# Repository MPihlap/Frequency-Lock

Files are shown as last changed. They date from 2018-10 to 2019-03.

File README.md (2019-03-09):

# Frequency-Lock

## Demonstration video:
https://www.youtube.com/watch?v=SHbAAHV13OE

## Overview
Result of a hardware project done for a course at University of Tartu. It is a custom board design built around the STM32F4 microcontroller. 
The system records audio in 0.2 second buffers, performs RFFT and analyzes the output to see if the correct note is being played.

The code is fully compatible with the STM32F4 Discovery board.

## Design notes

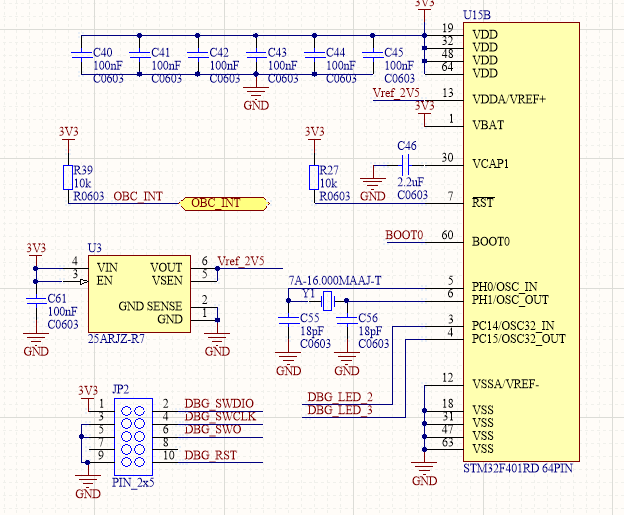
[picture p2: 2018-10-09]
docs/ˇF4power.PNG

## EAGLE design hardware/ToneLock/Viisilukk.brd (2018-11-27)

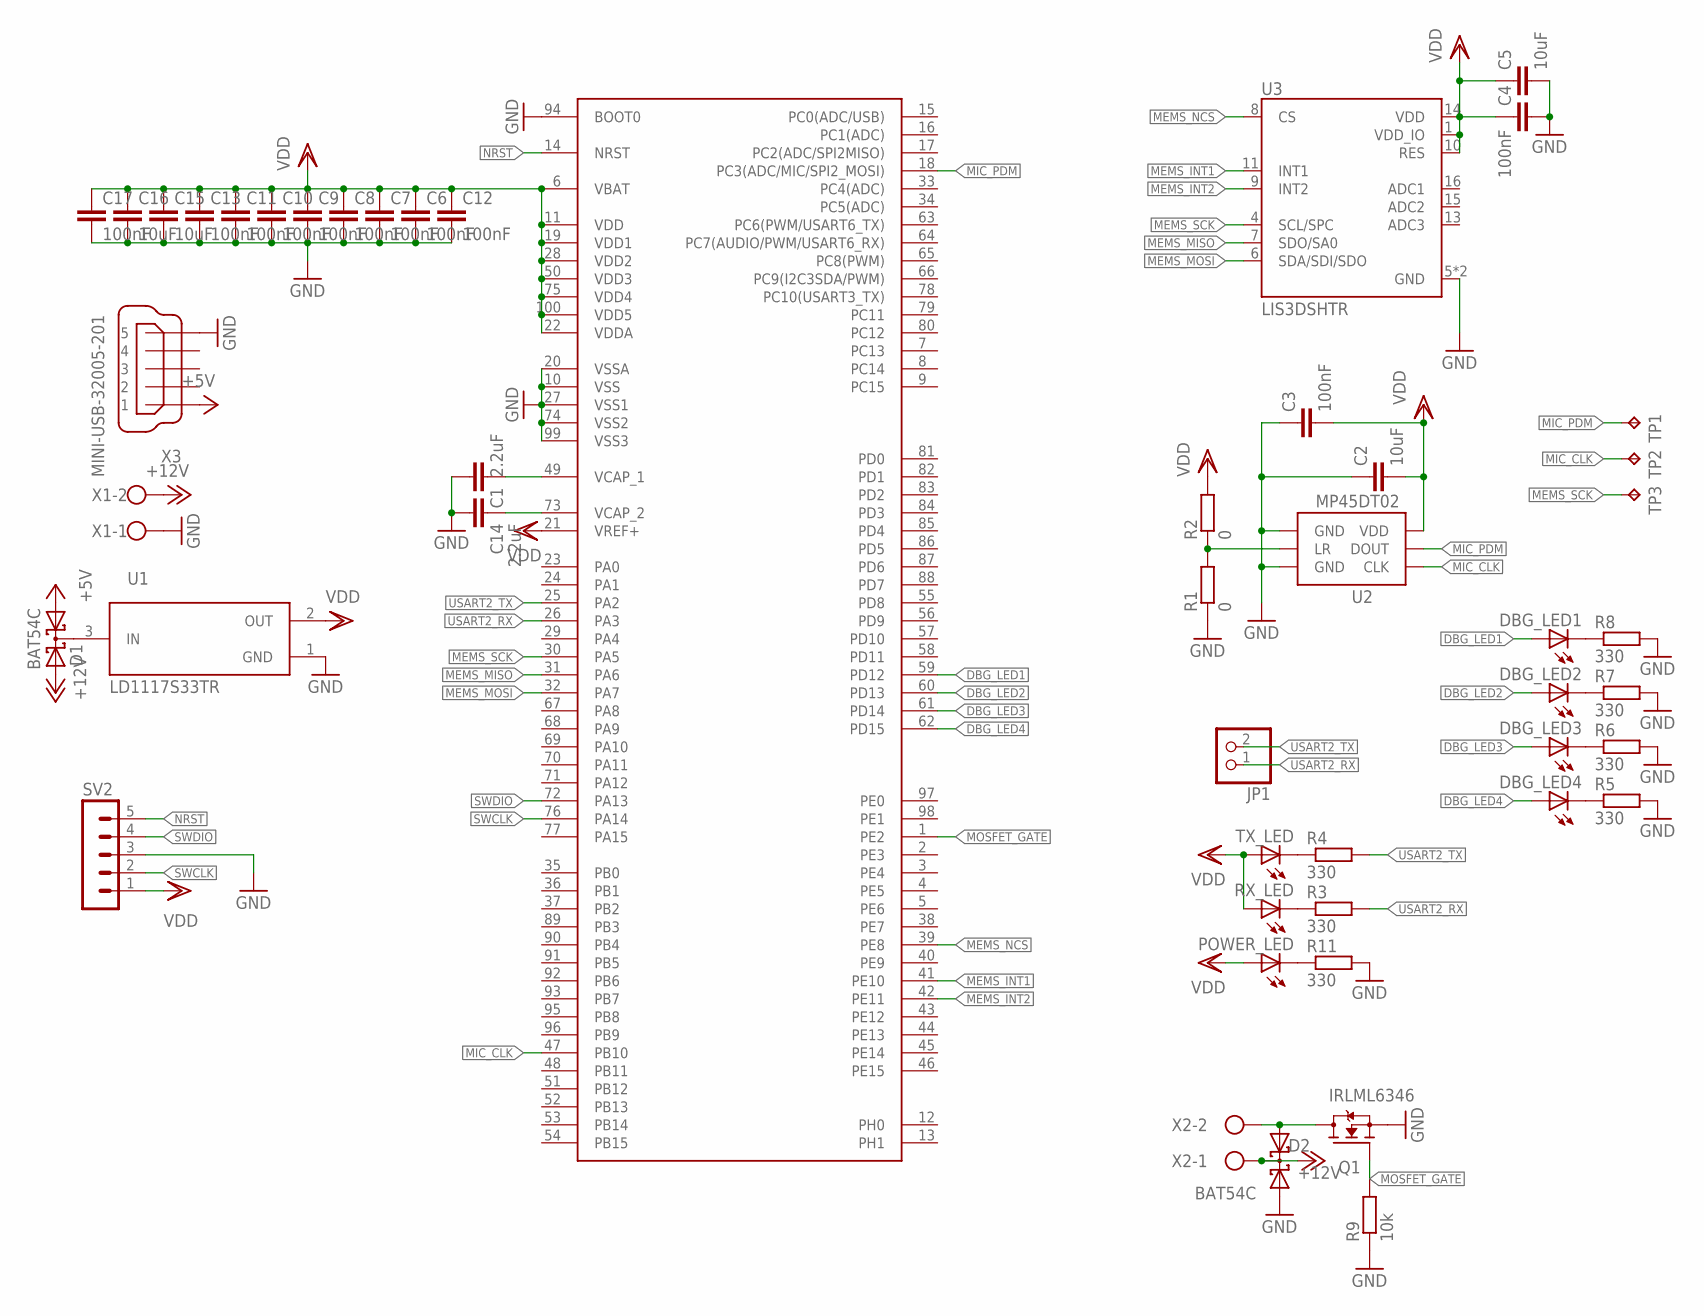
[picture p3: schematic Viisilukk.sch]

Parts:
C1, C14: 2.2uF; C0603
C2, C5, C15, C16: 10uF; C0805
C3, C4, C6, C7, C8, C9, C10, C11, C12, C13, C17: 100nF; C0603
D1, D2: BAT54C; SOT23
DBG_LED1, DBG_LED2, DBG_LED3, DBG_LED4: LEDCHIP-LED0603; CHIP-LED0603
JP1: PINHD-1X2; 1X02
POWER_LED: LEDCHIP-LED0603; CHIP-LED0603
Q1: IRLML6346; SOT23
R1, R2: 0; R0603
R3, R4, R5, R6, R7, R8, R11: 330; R0603
R9: 10k; R0603
RX_LED: LEDCHIP-LED0603; CHIP-LED0603
SV2: MA05-1
TP1, TP2, TP3: TPB2,54; B2,54
TX_LED: LEDCHIP-LED0603; CHIP-LED0603
U1: LD1117S33TR; SOT230P700X180-4N
U2: MP45DT02; ST_HLGA6
U3: LIS3DSHTR; LGA16R50P5X3_300X300X100N
U$1: STM32F407STM32D40X; LQFP100
X1, X2: W237-102
X3: MINI-USB-32005-201; 32005-201

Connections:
+5V: D1.1 (A1), X3.1
+12V: D1.2 (A2), D2.3 (CC), X1.2, X2.1
DBG_LED1: DBG_LED1.A, U$1.59 (PD12)
DBG_LED2: DBG_LED2.A, U$1.60 (PD13)
DBG_LED3: DBG_LED3.A, U$1.61 (PD14)
DBG_LED4: DBG_LED4.A, U$1.62 (PD15)
GND: C1.2, C2.1, C3.1, C4.2, C5.2, C6.2, C7.2, C8.2, C9.2, C10.2, C11.2, C12.2, C13.2, C14.2, C15.2, C16.2, C17.2, D2.1 (A1), Q1.2 (S), R1.1, R5.2, R6.2, R7.2, R8.2, R9.1, R11.2, SV2.3, U1.1 (GND), U2.1 (GND), U2.3 (GND), U3.5 (GND), U3.12 (GND), U$1.10 (VSS), U$1.20 (VSSA), U$1.27 (VSS1), U$1.74 (VSS2), U$1.94 (BOOT0), U$1.99 (VSS3), X1.1, X3.5
MEMS_INT1: U3.11 (INT1), U$1.41 (PE10)
MEMS_INT2: U3.9 (INT2), U$1.42 (PE11)
MEMS_MISO: U3.7 (SDO/SA0), U$1.31 (PA6)
MEMS_MOSI: U3.6 (SDA/SDI/SDO), U$1.32 (PA7)
MEMS_NCS: U3.8 (CS), U$1.39 (PE8)
MEMS_SCK: TP3.TP, U3.4 (SCL/SPC), U$1.30 (PA5)
MIC_CLK: TP2.TP, U2.4 (CLK), U$1.47 (PB10)
MIC_PDM: TP1.TP, U2.5 (DOUT), U$1.18 (PC3(ADC/MIC/SPI2_MOSI))
MOSFET_GATE: Q1.1 (G), R9.2, U$1.1 (PE2)
unnamed: POWER_LED.C, R11.1
unnamed: C14.1, U$1.73 (VCAP_2)
unnamed: R1.2, R2.1, U2.2 (LR)
unnamed: R3.1, RX_LED.C
unnamed: C1.1, U$1.49 (VCAP_1)
unnamed: D1.3 (CC), U1.3 (IN)
unnamed: R4.1, TX_LED.C
unnamed: DBG_LED4.C, R5.1
unnamed: DBG_LED3.C, R6.1
unnamed: DBG_LED2.C, R7.1
unnamed: DBG_LED1.C, R8.1
unnamed: D2.2 (A2), Q1.3 (D), X2.2
NRST: SV2.5, U$1.14 (NRST)
SWCLK: SV2.2, U$1.76 (PA14)
SWDIO: SV2.4, U$1.72 (PA13)
USART2_RX: JP1.1, R3.2, U$1.26 (PA3)
USART2_TX: JP1.2, R4.2, U$1.25 (PA2)
VDD: C2.2, C3.2, C4.1, C5.1, C6.1, C7.1, C8.1, C9.1, C10.1, C11.1, C12.1, C13.1, C15.1, C16.1, C17.1, POWER_LED.A, R2.2, RX_LED.A, SV2.1, TX_LED.A, U1.2 (OUT), U2.6 (VDD), U3.1 (VDD_IO), U3.10 (RES), U3.14 (VDD), U$1.6 (VBAT), U$1.11 (VDD), U$1.19 (VDD1), U$1.21 (VREF+), U$1.22 (VDDA), U$1.28 (VDD2), U$1.50 (VDD3), U$1.75 (VDD4), U$1.100 (VDD5)

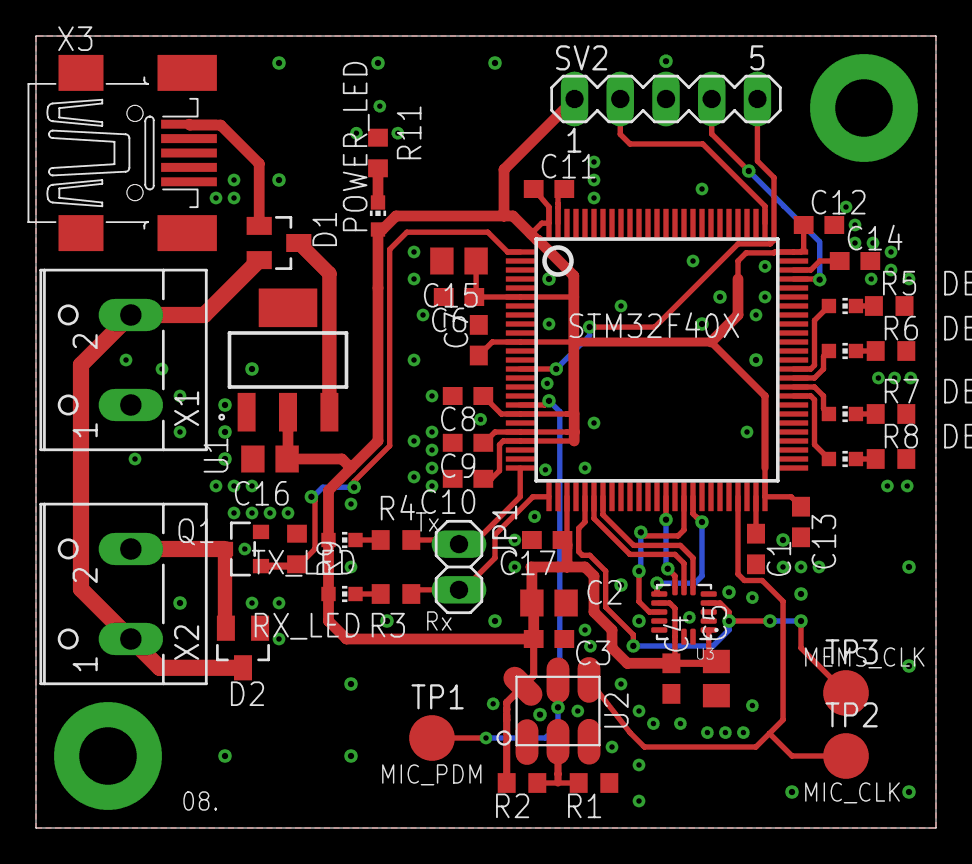
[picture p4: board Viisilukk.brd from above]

Board: 2 copper layers, 50.0 x 44.0 mm, 49 parts (0 on the bottom side), 34 nets.

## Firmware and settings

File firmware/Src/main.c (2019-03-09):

/**
  ******************************************************************************
  * @file           : main.c
  * @brief          : Main program body
  ******************************************************************************
  * This notice applies to any and all portions of this file
  * that are not between comment pairs USER CODE BEGIN and
  * USER CODE END. Other portions of this file, whether
  * inserted by the user or by software development tools
  * are owned by their respective copyright owners.
  *
  * Copyright (c) 2019 STMicroelectronics International N.V.
  * All rights reserved.
  *
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
  ******************************************************************************
  */
/* Includes ------------------------------------------------------------------*/
#include "main.h"
#include "stm32f4xx_hal.h"
#include "pdm2pcm.h"

/* USER CODE BEGIN Includes */
#include "arm_math.h"
#include <math.h>
#include "note_freq.h"
/* USER CODE END Includes */

CRC_HandleTypeDef hcrc;

I2S_HandleTypeDef hi2s2;

SPI_HandleTypeDef hspi1;

TIM_HandleTypeDef htim6;

UART_HandleTypeDef huart2;

/* USER CODE BEGIN PV */

/* USER CODE END PV */

void SystemClock_Config(void);
static void MX_GPIO_Init(void);
static void MX_SPI1_Init(void);
static void MX_USART2_UART_Init(void);
static void MX_I2S2_Init(void);
static void MX_CRC_Init(void);
static void MX_TIM6_Init(void);

/* USER CODE BEGIN PFP */
// static void SPI2_NVIC_INIT(void);
/* USER CODE END PFP */

/* USER CODE BEGIN 0 */
uint16_t PDM_BUF_1[PDM_BUF_SIZE];  // PDM buffer1
uint16_t PCM_BUF_1[PCM_BUF_SIZE];  // PCM buffer1
uint16_t PCM_BUF_2[PCM_BUF_SIZE];  // PCM buffer2
float32_t fft_output_buffer[PCM_BUF_SIZE * 2];
float32_t fft_input_buffer[PCM_BUF_SIZE];
float32_t fft_mag_buffer[PCM_BUF_SIZE];
uint32_t local_pcm_pointer = 0;  // Keeps track of PCM buffer
uint8_t PCM_switch_flag = 0;
uint16_t *current_PCM_buffer;  // Pointer to array to be recorded to
uint8_t RECORD_ENABLE = 0;     // Recording control flag
uint8_t open_lock_counter = 0;
uint32_t sequence[] = MY_HEART_WILL_GO_ON;
// Desired index of maximum magnitude, initially 100 = 781.25 ... 789 Hz
uint32_t desiredIndex = 100;
uint16_t error = 3;  // How many neighbouring indexes will be considered legit
arm_rfft_fast_instance_f32 S;

/* USER CODE END 0 */

/**
  * @brief  The application entry point.
  *
  * @retval None
  */
int main(void) {
  /* USER CODE BEGIN 1 */
  //__HAL_DBGMCU_UNFREEZE_IWDG();
  /* USER CODE END 1 */

  /* MCU
   * Configuration----------------------------------------------------------*/

  /* Reset of all peripherals, Initializes the Flash interface and the Systick.
   */
  HAL_Init();

  /* Configure the system clock */
  SystemClock_Config();

  /* Initialize all configured peripherals */
  MX_GPIO_Init();
  MX_SPI1_Init();
  MX_USART2_UART_Init();
  MX_I2S2_Init();
  MX_CRC_Init();
  MX_PDM2PCM_Init();
  MX_TIM6_Init();
  /* USER CODE BEGIN 2 */
  arm_rfft_fast_init_f32(&S, PCM_BUF_SIZE);
  desiredIndex = GET_DESIRED_INDEX(sequence[open_lock_counter]);
  error = ERROR_INDEX(sequence[open_lock_counter]);
  LOCK_ENABLE();
  // SPI2_NVIC_INIT();
  HAL_GPIO_WritePin(GPIOE, SPI1_NCS_PIN, GPIO_PIN_SET);
  RECORD_ENABLE = 1;  // Enable I2S reading
  HAL_GPIO_WritePin(LED_PORT, LED2_PIN, GPIO_PIN_SET);
  uint8_t PCM_switch_prev = PCM_switch_flag;

  current_PCM_buffer = PCM_BUF_1;
  volatile float32_t maxmag;
  volatile uint32_t index;

  HAL_I2S_Receive_IT(&hi2s2, PDM_BUF_1, 64);

  /* USER CODE END 2 */

  /* Infinite loop */
  /* USER CODE BEGIN WHILE */
  uint16_t handshake[4] = {1000, 1100, 1200, 1300};

  while (1) {
    // Check if we have a full buffer of PCM data
    if (PCM_switch_flag != PCM_switch_prev) {
      PCM_switch_prev = PCM_switch_flag;  // Set flag to new value
      // Convert data to float for signal processing
      for (uint16_t i = 0; i < PCM_BUF_SIZE; i++) {
        fft_input_buffer[i] = (float32_t)PCM_BUF_1[i];
      }

      // Perform real fft
      arm_rfft_fast_f32(&S, fft_input_buffer, fft_output_buffer, 0);
      // Find magnitudes of complex values
      arm_cmplx_mag_f32(fft_output_buffer, fft_mag_buffer, PCM_BUF_SIZE);
      // Find maximum magnitude, ignoring first element
      arm_max_f32(&(fft_mag_buffer[1]), PCM_BUF_SIZE - 1, &maxmag, &index);

      // Only react to high enough magnitudes
      if (maxmag > 50) {
        // Check if the highest magnitude corresponds to the desired frequency
        if ((index > desiredIndex - error) && (index < desiredIndex + error)) {
          if (open_lock_counter == 0) {
            HAL_TIM_Base_Start_IT(&htim6);
            HAL_GPIO_WritePin(GPIOD, LED4_PIN, GPIO_PIN_SET);
          }
          HAL_GPIO_WritePin(LED_PORT, LED3_PIN, GPIO_PIN_SET);
          // Move to next stage
          open_lock_counter++;
          desiredIndex = GET_DESIRED_INDEX(sequence[open_lock_counter]);
          error = ERROR_INDEX(sequence[open_lock_counter]);

          // Success! open lock
          if (open_lock_counter >= LOCK_STAGES) {
            LOCK_DISABLE();
            HAL_GPIO_WritePin(LED_PORT, LED1_PIN, GPIO_PIN_SET);
            HAL_GPIO_WritePin(LED_PORT, LED2_PIN, GPIO_PIN_SET);
            HAL_GPIO_WritePin(LED_PORT, LED3_PIN, GPIO_PIN_SET);
            HAL_GPIO_WritePin(LED_PORT, LED4_PIN, GPIO_PIN_SET);
            // Start timer to keep lock open for 5 seconds
            htim6.Instance->CNT = 0;
            HAL_TIM_Base_Start_IT(&htim6);
          }
        }
      }

      // Resume recording after signal processing
      RECORD_ENABLE = 1;
      __HAL_I2S_CLEAR_OVRFLAG(&hi2s2);
      HAL_I2S_Receive_IT(&hi2s2, PDM_BUF_1, 64);
    }
    HAL_Delay(10);

    /* USER CODE END WHILE */

    /* USER CODE BEGIN 3 */
  }
  /* USER CODE END 3 */
}

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
/* USER CODE BEGIN 4 */

void HAL_TIM_PeriodElapsedCallback(TIM_HandleTypeDef *htim) {
  HAL_GPIO_TogglePin(GPIOD, LED4_PIN);
  HAL_GPIO_WritePin(LED_PORT, LED1_PIN, GPIO_PIN_RESET);
  HAL_GPIO_WritePin(LED_PORT, LED2_PIN, GPIO_PIN_RESET);
  HAL_GPIO_WritePin(LED_PORT, LED3_PIN, GPIO_PIN_RESET);
  HAL_GPIO_WritePin(LED_PORT, LED4_PIN, GPIO_PIN_RESET);
  HAL_TIM_Base_Stop_IT(&htim6);
  LOCK_ENABLE();
  open_lock_counter = 0;
  desiredIndex = GET_DESIRED_INDEX(sequence[0]);
  error = ERROR_INDEX(sequence[open_lock_counter]);
}

void HAL_I2S_RxCpltCallback(I2S_HandleTypeDef *hi2s) {
  PDM_Filter(PDM_BUF_1, &PCM_BUF_1[local_pcm_pointer], &PDM1_filter_handler);

  HAL_GPIO_WritePin(LED_PORT, LED2_PIN, GPIO_PIN_RESET);
  HAL_GPIO_WritePin(LED_PORT, LED3_PIN, GPIO_PIN_RESET);
  local_pcm_pointer = local_pcm_pointer + 16;  // The filter returns 16 samples
  if (local_pcm_pointer == PCM_BUF_SIZE) {
    local_pcm_pointer = 0;
    RECORD_ENABLE = 0;
    HAL_GPIO_WritePin(GPIOD, LED2_PIN, GPIO_PIN_RESET);
    PCM_switch_flag ^= 1;
  }
  if (RECORD_ENABLE == 1) {
    HAL_StatusTypeDef result;
    result = HAL_I2S_Receive_IT(&hi2s2, PDM_BUF_1, DECIMATION_FACTOR);

    if (result == HAL_OK) {
      HAL_GPIO_WritePin(GPIOD, LED2_PIN, GPIO_PIN_SET);
    } else {
      HAL_GPIO_WritePin(GPIOD, LED2_PIN, GPIO_PIN_RESET);
    }
  }
}

/* USER CODE END 4 */
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


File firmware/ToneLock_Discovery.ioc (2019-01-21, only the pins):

Mcu.UserName=STM32F407VGTx
PA13.GPIO_Label=SWDIO
PA13.Signal=SYS_JTMS-SWDIO
PA14.GPIO_Label=SWCLK
PA14.Signal=SYS_JTCK-SWCLK
PA2.Signal=USART2_TX
PA3.Signal=USART2_RX
PA4.GPIO_Label=I2S3_WS [CS43L22_LRCK]
PA4.Signal=I2S3_WS
PA5.GPIO_Label=SPI1_SCK [LIS302DL_SCL/SPC]
PA5.Signal=SPI1_SCK
PA6.GPIO_Label=SPI1_MISO [LIS302DL_SDO]
PA6.Signal=SPI1_MISO
PA7.GPIO_Label=SPI1_MOSI [LIS302DL_SDA/SDI/SDO]
PA7.Signal=SPI1_MOSI
PB10.GPIO_Label=CLK_IN [MP45DT02_CLK]
PB10.Signal=I2S2_CK
PB12.Signal=I2S2_WS
PB2.GPIO_Label=BOOT1
PB2.Signal=GPIO_Input
PC0.GPIO_Label=OTG_FS_PowerSwitchOn
PC0.Signal=GPIO_Output
PC14-OSC32_IN.GPIO_Label=PC14-OSC32_IN
PC14-OSC32_IN.Signal=RCC_OSC32_IN
PC15-OSC32_OUT.GPIO_Label=PC15-OSC32_OUT
PC15-OSC32_OUT.Signal=RCC_OSC32_OUT
PC3.Signal=I2S2_SD
PD12.GPIO_Label=LD4 [Green Led]
PD12.Signal=GPIO_Output
PD13.GPIO_Label=LD3 [Orange Led]
PD13.Signal=GPIO_Output
PD14.GPIO_Label=LD5 [Red Led]
PD14.Signal=GPIO_Output
PD15.GPIO_Label=LD6 [Blue Led]
PD15.Signal=GPIO_Output
PE1.GPIO_Label=MEMS_INT2 [LIS302DL_INT2]
PE1.Signal=GPXTI1
PE2.Signal=GPIO_Output
PE3.GPIO_Label=CS_I2C/SPI [LIS302DL_CS_I2C/SPI]
PE3.Signal=GPIO_Output
PH0-OSC_IN.GPIO_Label=PH0-OSC_IN
PH0-OSC_IN.Signal=RCC_OSC_IN
PH1-OSC_OUT.GPIO_Label=PH1-OSC_OUT
PH1-OSC_OUT.Signal=RCC_OSC_OUT

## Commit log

2018-09-24 UART test, not working yet
    [main.c]
2018-10-01 Added schematic for discovery board
2018-10-08 Added Eagle project for hardware
    [MCU.brd, MCU.sch]
2018-10-08 Added accelerometer, microphone into schematic and added libraries
    [MCU.sch]
2018-10-08 Renamed datasheets and Added UART pins
    [MCU.brd, MCU.sch]
2018-10-08 Changed UART to use USART2
    [MCU.brd, MCU.sch]
2018-10-09 Synced board
2018-10-09 Changed VCC header
    [MCU.brd, MCU.sch]
2018-10-16 Added BOOT0 and NRST setups, power LED, Debugger
    [MCU.brd, MCU.sch]
2018-10-23 Completed schematic
    [MCU.brd, MCU.sch]
2018-11-06 Fixed MOSFET switch, grouped all components
    [MCU.brd, MCU.sch]
2018-11-12 All VCC and signals routed, GND TODO
    [MCU.brd]
2018-11-12 Added final signal route
    [MCU.brd]
2018-11-13 Schematic ready for pour, rewired all supply lines
    [MCU.brd, MCU.sch]
2018-11-20 Routed, polygon poured, ready in theory
    [MCU.brd, MCU.sch]
2018-11-20 Board now 50x44
    [MCU.brd]
2018-11-27 Ready for polygon
    [MCU.brd, MCU.sch]
2018-11-27 Hardware ready to generate gerber
    [MCU.brd, MCU.sch]
2018-11-27 Renamed to Viisilukk, final design
    [Viisilukk.brd, Viisilukk.sch]
2018-12-21 Implemented pdm filter and reworked main
    [main.c, main.h]
2019-01-16 Tried new approach to recursive interrupts, didn't work
    [main.c]
2019-01-17 Not working closer to hardware solution
    [main.c]
2019-01-17 This should work in theory, currently overrun bug
    [main.c]
2019-01-25 Added led blinking to signal progression, fixed timer
    [main.c]
2019-01-25 Added error measurements in cents
    [main.c, main.h]
2019-01-25 Fixed float division bug
    [main.h]
2019-01-25 Fixed notes in my heart will go on
    [main.c, main.h]
2019-03-09 Refactored project structure and removed broken code
    [ToneLock_Discovery.ioc, main.c, main.h]
2019-03-15 Fixed names of src and inc folders
    [main.c, main.h]

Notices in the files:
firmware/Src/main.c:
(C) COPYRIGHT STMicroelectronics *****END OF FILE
